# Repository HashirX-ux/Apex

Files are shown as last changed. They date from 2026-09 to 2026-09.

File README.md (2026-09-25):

# Apex


[]()
[]()
[]()
[]()
[]()
[]()`

---

## What is it?







## CAD





Apex is a custom **112 key full size** wireless mechanical keyboard I designed from the ground up after building a macropad and deciding a store bought board would never feel like mine.

The PCB is designed in **KiCad**, the case in **FreeCAD**, and the firmware is on **ZMK**. 

On top of a standard full size layout it adds:

- a **0.91" SSD1306 OLED** (128×32, I²C) for layer / battery / connection status
- an **EC11 rotary encoder** with push switch (volume and extras)
- an onboard **buzzer** driven by a 2N3904
- **per-key SK6812 Mini E** reverse mount RGB

---

## Why I built it

I wanted a Keyboard that belongs to me not to any company so I build my own keyboard. 

---

## Features

- 112 keys, full size layout (ANSI 104 + 8 extra keys)
- 8×14 col2row matrix
- Wireless BLE 5.0 via Nordic nRF52840 (AQFN- 73)
- USB C wired + wireless dual mode
- Per-key SK6812 Mini E RGB, reverse mounted
- Kailh MX hot-swap sockets  
- 0.91" OLED (SSD1306, 128×32, I²C)
- EC11 rotary encoder with push switch
- Onboard buzzer (2N3904 driver)
- 3.7 V LiPo 1500 mAh with MCP73831 charger
- 74AHCT125 level shifter for LED data (3.3 V → 5 V)
- USBLC6 2SC6 ESD protection on USB D+/D−
- 32 MHz crystal for the nRF52840
- ZMK firmware (USB + BLE, battery reporting, OLED, encoder, RGB)
- 2-layer PCB, KiCad, JLCPCB fabrication
- Custom 3D printed case designed in FreeCAD

---

ZMK is currently targeted at `nice_nano_v2` as a bring up stand in. The PCB carries a **bare nRF52840** (not a Pro Micro module). Pin mapping on the real board is still being finished see [Firmware](#flash-the-firmware).

---

## How to Build

### Order the PCB

1. Go to [JLCPCB](https://jlcpcb.com)
2. Upload the Gerbers from `pcb/gerber/gerber.rar`
3. 2-layer, FR 4, **1.6 mm**, HASL or **ENIG** (ENIG recommended for hot-swap pads and the AQFN-73)
4. Minimum order is 5 boards
5. Order a stencil for the nRF52840, SK6812 Mini-E, and other SMD parts the AQFN-73 is not a hand-solder-first footprint

### Flash the Firmware

Firmware lives in [`frimware/`](frimware/) and is a **ZMK skeleton**, not the final keymap.

1. Fork this repo (or copy `frimware/` into a [ZMK config](https://zmk.dev/docs/user-setup) repo)
2. Current build target in `frimware/build.yaml`:

   ```yaml
   include:
     - board: nice_nano_v2
       shield: apex
   ```

3. Edit the keymap at `frimware/config/apex.keymap`
4. Push GitHub Actions builds the `.uf2`
5. Download the artifact, double-tap reset to enter the bootloader, drag the `.uf2` onto the drive that appears

The overlay (`frimware/config/boards/shields/apex/apex.overlay`) is still a 5×14 bring up matrix. The PCB is **8×14 / 112 keys**. Next step is mapping the real nRF52840 pins, OLED, encoder, buzzer, and the 112 LED chain.

## BOM

> Estimated total: **~$230 USD** can drop to **$170–$200** buying locally and skipping extras (second switch pack, spare LEDs, extra PCBs).

Prices are typical AliExpress pack prices as of 2026. You buy the pack; you do not need every piece in it. Shipping not included.

| Component | Spec | Qty | Price | Notes | Link |
|---|---|---|---|---|---|
| Microcontroller | nRF52840-QIAA, AQFN-73 | ×1 | $5.00 | Bare Nordic SoC — BLE 5.0, 7×7 mm | [Buy](https://www.aliexpress.com/item/1005009698070392.html) |
| 74AHCT125 level shifter | TSSOP-14 | ×1 | $2.52 | Pack of 10 — LED data 3.3 V → 5 V | [Buy](https://www.aliexpress.com/item/1005008171122183.html) |
| MCP73831 LiPo charger | MCP73831-2-MC, DFN-8 3×2 mm | ×1 | $2.50 | Pack of 10 — **DFN-8 footprint**, not SOT-23-5 | [Buy](https://www.aliexpress.com/item/1005007439657191.html) |
| USBLC6-2SC6 ESD | SOT-23-6 | ×1 | $1.50 | Pack of 10 — USB D+/D− | [Buy](https://www.aliexpress.com/item/32807108222.html) |
| MX mechanical switches | 5-pin PCB mount | ×112 | $32.00 | Pack of 110–120 — Gateron / any MX 5-pin | [Buy](https://www.aliexpress.com/item/1005006091988869.html) |
| Kailh hot-swap socket | MX compatible, CPG151101S11 | ×112 | $14.00 | Pack of 100 × 2 | [Buy](https://www.aliexpress.com/item/1005006105603269.html) |
| SK6812 Mini-E RGB LED | Reverse mount, 3.2×2.8 mm | ×112 | $27.00 | Pack of 100 × 2 — buy 200, use 112 + spares | [Buy](https://www.aliexpress.com/item/1005004249903121.html) |
| 1N4148W matrix diode | SOD-123 | ×112 | $3.00 | Pack of 100 × 2 | [Buy](https://www.aliexpress.com/item/1005010728396328.html) |
| EC11 rotary encoder | 20 mm, with push switch | ×1 | $2.00 | Pack of 5 | [Buy](https://www.aliexpress.com/item/1005006460161288.html) |
| Rotary knob | Aluminum, 6 mm D-shaft, 20 mm | ×1 | $2.00 | 2 pieces | [Buy](https://www.aliexpress.com/item/4001091267351.html) |
| Reset button | SMD tactile, CK KMR2 | ×1 | $1.50 | Pack of 30 | [Buy](https://www.aliexpress.com/item/4001107416458.html) |
| OLED display | 0.91" 128×32 SSD1306 I²C | ×1 | $2.50 | ER-OLED0.91, address 0x3C | [Buy](https://www.aliexpress.com/item/1005004375650245.html) |
| Buzzer | 12×9.5 mm, 5 V | ×1 | $1.80 | Pack of 10 — matches 12×9.5 RM7.6 footprint | [Buy](https://www.aliexpress.com/item/4000829554492.html) |
| 2N3904 transistor | TO-92 | ×1 | $1.40 | Pack of 50 — buzzer driver | [Buy](https://www.aliexpress.com/w/wholesale-2n3904-transistor.html) |
| 32 MHz crystal | SMD 2016, 4-pin | ×1 | $1.80 | Pack of 10 — nRF52840 HFCLK | [Buy](https://www.aliexpress.com/w/wholesale-32mhz-crystal.html) |
| Status LED | 0603 SMD | ×1 | $1.00 | Pack of 100 — charger / power indicator | [Buy](https://www.aliexpress.com/w/wholesale-0603-smd-led.html) |
| Resistor 10 kΩ | 0603 | ×3 | $1.20 | Pack of 300 — I²C / reset pull-ups | [Buy](https://www.aliexpress.com/item/1005011779883974.html) |
| Resistor 5.1 kΩ | 0603 | ×2 | $1.30 | Pack of 300 — USB-C CC1/CC2 | [Buy](https://www.aliexpress.com/item/1005011779883974.html) |
| Resistor 330 Ω | 0603 | ×1 | $2.00 | Pack of 500 — buzzer base / LED | [Buy](https://www.aliexpress.com/item/1005005700395390.html) |
| Resistor 1 kΩ | 1206 + 0805 | ×2 | $1.20 | Pack of 300 — PROG / current limit | [Buy](https://www.aliexpress.com/item/1005011779883974.html) |
| Capacitor 100 nF | 0805 | ×119 | $2.00 | Pack of 200 — 112 LED + MCU decoupling | [Buy](https://www.aliexpress.com/item/1005007660078779.html) |
| Capacitor 12 pF | 0402 | ×2 | $1.50 | Pack of 100 — crystal load | [Buy](https://www.aliexpress.com/w/wholesale-0402-12pf-capacitor.html) |
| USB-C receptacle 16P | GCT USB4105 SMD | ×1 | $4.50 | Pack of 5 | [Buy](https://www.aliexpress.com/item/1005005581945089.html) |
| JST PH 2-pin | PH2.0, B2B-PH-K vertical | ×1 | $2.00 | Pack of 2 — battery connector | [Buy](https://www.aliexpress.com/item/1005010615395743.html) |
| Polyfuse 500 mA | Resettable, 1206 | ×1 | $1.70 | Pack of 10 | [Buy](https://www.aliexpress.com/item/1005005235906949.html) |
| LiPo 3.7 V 1500 mAh | JST PH 2.0 | ×1 | $5.80 | Size to fit the case tray | [Buy](https://www.aliexpress.com/item/1005010110802624.html) |
| Keycap set | PBT, full-size MX | ×104+ | $26.00 | 104-key set; extras needed for 112 | [Buy](https://www.aliexpress.com/w/wholesale-104-keycap-set.html) |
| PCB fabrication | 2-layer, FR-4, 1.6 mm, HASL/ENIG | ×5 boards | $32.00 | Full-size board — ENIG preferred | [JLCPCB](https://cart.jlcpcb.com/quote) |
| 3D print — case | FDM PETG / SLA resin | ×1 | $42.00 | FreeCAD sources in `cad/` — local print is cheaper | [JLC3DP](https://jlc3dp.com/3d-printing-quote) |
| M3 screws | M3 × 8 mm countersunk | ×10 | $1.00 | Pack of 50 | [Buy](https://www.aliexpress.com/item/1005008810897680.html) |
| M3 standoffs | M3 × 4–6 mm | ×10 | $1.00 | Pack of 50 | [Buy](https://www.aliexpress.com/item/1005008810897680.html) |

**BOM notes**

- The charger footprint on the PCB is **DFN-8 (MCP73831-2-MC)**. A SOT-23-5 MCP73831 will not fit without a bodge.
- SK6812 Mini-E must be the **reverse-mount** Mini-E, not SK6812 Mini or WS2812B 3535.
- Hot-swap sockets are **Kailh MX** (CPG151101S11), 1.00u. Stabilizers are still required on 2U+ keys (not listed — use your usual plate/PCB mount Cherry-style stabs).
- nRF52840 can run from VDDH (2.5–5.5 V high-voltage mode), which is why there is no separate 3.3 V LDO on this rev. LEDs are 5 V (`LED_5V` / VBUS).
- PROG resistor on the MCP73831 sets charge current (`IREG ≈ 1000 / RPROG`). 1 kΩ ≈ 1 A; 2 kΩ ≈ 500 mA. 500 mA is gentler on a 1500 mAh cell.

---

## Repository

```text
Apex/
├── cad/                  FreeCAD case + STEP
│   ├── APex cad.FCStd
│   └── .step
├── frimware/             ZMK config (skeleton)
│   ├── build.yaml
│   └── config/
│       ├── apex.conf
│       ├── apex.keymap
│       └── boards/shields/apex/
├── pcb/
│   ├── apex-pcb_design.kicad_sch
│   ├── apex-pcb_design.kicad_pcb
│   ├── LED-Design.kicad_sch
│   └── gerber/gerber.rar
├── Journal.md            Build log
└── LICENSE               MIT
```

---

## Credits

- [KiCad](https://www.kicad.org/)   PCB design
- [ZMK Firmware](https://zmk.dev/)   open-source wireless keyboard firmware
- [FreeCAD](https://www.freecad.org/)  case design
- [Nordic Semiconductor](https://www.nordicsemi.com/)   nRF52840
- [nice!nano](https://nicekeyboards.com/nice-nano/)   ZMK bring-up target
- Guides that got this off the ground: [nice!nano docs](https://nicekeyboards.com/docs/nice-nano/), [JLCPCB keyboard PCB guide](https://jlcpcb.com/blog/pcb-keyboards-design-guide), [Masterzen keyboard design series](https://www.masterzen.fr/2020/05/03/designing-a-keyboard-part-1/)

Made by **Hashir**  2026

---

## License

[MIT](LICENSE)

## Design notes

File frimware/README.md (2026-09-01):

# Apex firmware

this is the vibe check for the apex keyboard build

104 keys
wireless
nrf52840 vibe
nice nano style board
oled
rotary knob
buzzer
rgb
battery charging stuff

this is just the skeleton not the full final firmware
base setup is in zmk
main pieces are in the config folder

build yaml
apex conf
apex keymap
apex overlay

next up is mapping the real pcb pins and finishing the full key layout

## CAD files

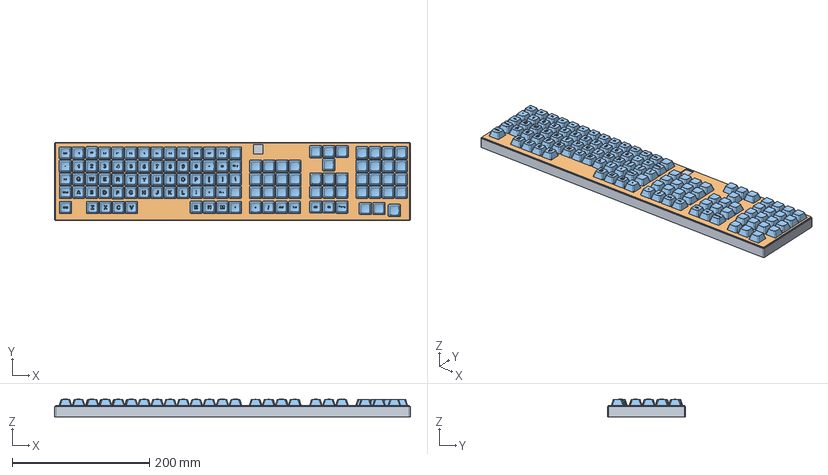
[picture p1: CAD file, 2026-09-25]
cad/keyboard_assembly.FCStd
519.4 x 114.3 x 25.9 mm
BaseTray
KeyboardPlate
KeyCaps
KeyLegends

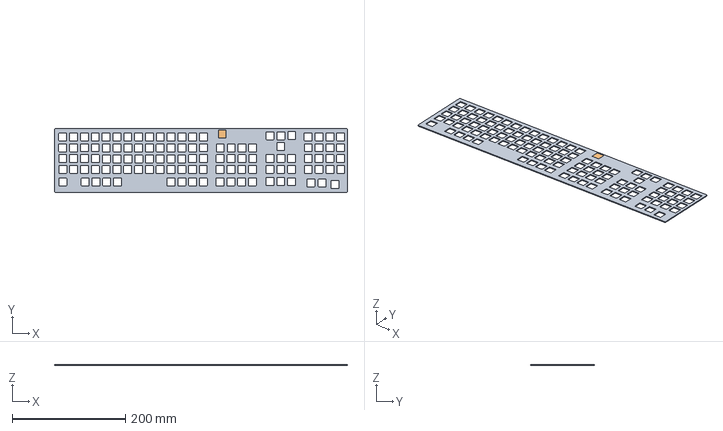
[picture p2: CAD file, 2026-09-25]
cad/plate.FCStd
516.6 x 112.1 x 1.50 mm

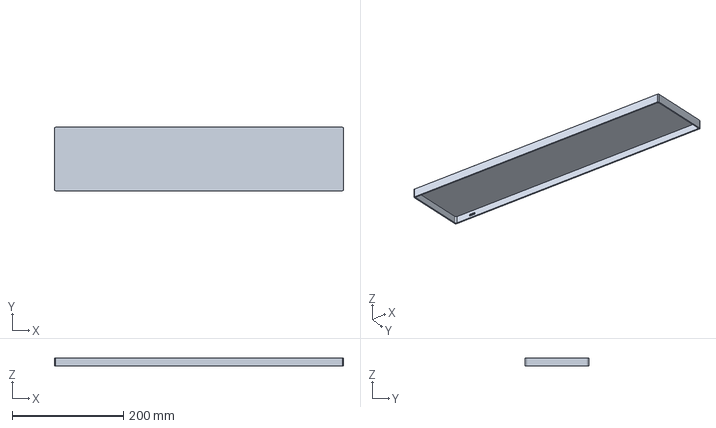
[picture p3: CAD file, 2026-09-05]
cad/APex cad.FCStd
519.4 x 114.3 x 15.0 mm

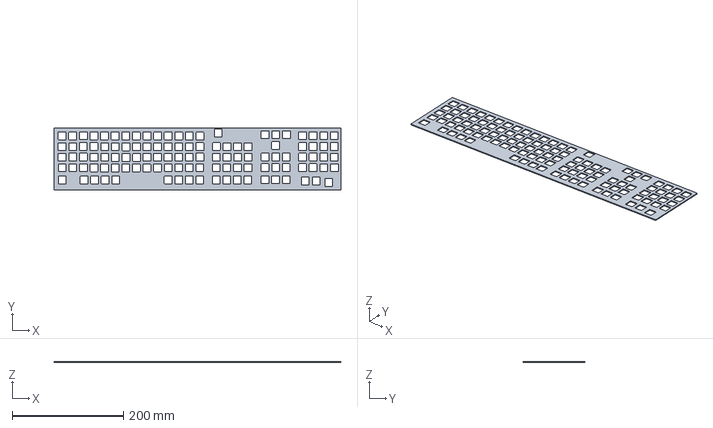
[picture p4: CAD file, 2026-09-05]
cad/apex_plate.step
516.6 x 112.1 x 1.50 mm

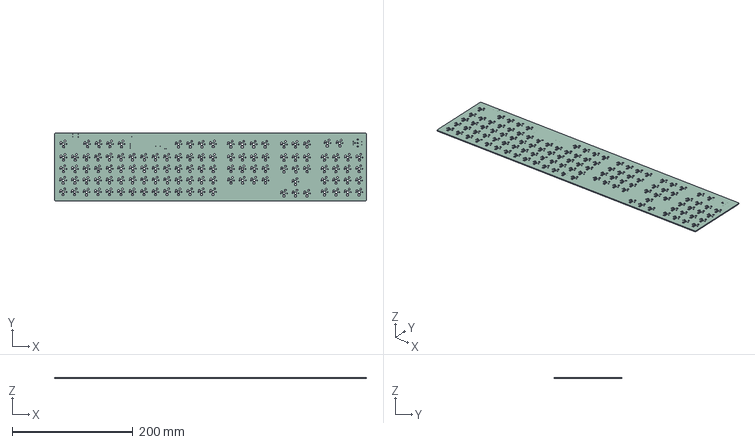
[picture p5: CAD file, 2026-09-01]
cad/.step
516.6 x 112.1 x 1.51 mm

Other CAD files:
cad/APex cad-Body.step

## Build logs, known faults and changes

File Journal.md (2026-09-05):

# Project Journal

**Project Name:** Apex  
**Start Date:** 2026-01-08  
**Status:** Completed

## Overview
Apex is a wireless mechanical keyboard built for productivity and daily tasks.

## Recent Entries

### 2026-01-08 - First Journal Entry

**What I did today:**

So This is my first time creating a keyboard. I have created a macropad before so I thought why not built a full keyboard of my own. So I did it duhh.. it was difficult but somehow I did it.. 
<br>

I am gonna start my research now.. Gonna start with the number of keys that i am gonna use: 

<br>
Guess I am gonna use standard keyboard keys which are 104 for the US/Canada type: 

<br>
So I researched a not for the MCU that I wass gonna use for my keybord and I found the nicennao v2 the best for that as it already contains built in crystal oscillator and voltage regulator which us gonna help me manage my schematic and make it less complexx..
<br>
So here are my main components that I am gonna use for my keyboard: 
<br>

1- MCU: nicenano! v2

<br>

2- 104-standard keys

<br>

3- OLED 0.91 inch

<br>

4- RotaryEncoder

<br>

5- Buzzer


5- Diodes

<br>

6- DeCoupling Caps

<br>

7- Reset Swtich
<br>

Now I gotta understand all of the datasheeeets.. Lets start by nicennao.. Wish me luck gngng..I am gonna use the official nicennao doc for this research: 
<br>
https://nicekeyboards.com/docs/nice-nano/
<br>
Found this keyboard config guide: https://www.nextpcb.com/blog/how-to-design-mechanical-keyboard-pcbs-with-kicad

<br>
One of the best guide I found out there gng .. 
<br>
https://www.modmusings.com/how-to-build-a-mechanical-keyboard
<br>
Thanks again the og documentation.. This is gonna help alot

<br>
So this is the schematic for the OLED i am gonna use its OLED 0.91: 

<br>
Didnt expected my rotary encoder to look like this under the hood: 

<br>
This would really help in designing the 3D cover case for my keyboard.. 

<br>
YOOO gng i think I just found a goldmine thank god i was looking for this: 
https://www.masterzen.fr/2020/05/03/designing-a-keyboard-part-1/
So Now I am Done with the research I am gonna start building the shcmeatic of my keyvaord and then The Final PCB design.. Wish me luck boisss.. 
<br>
### 2026-02-08 - First Journal Entry

**What I did today:**
So Today I am gonna start building the shcematic of my keyboard.. I am gonna use the official guide from PCBWay and JLCPCB for their keyboard design guide: 
<br>
https://jlcpcb.com/blog/pcb-keyboards-design-guide
<br>
So I am gonna build the schematic using this layout: 

<br>
The MCU looks good.. its nice and nano nicenano!!!

<br>
So this is my first key and I have to compleye like 112 of them.. wish me luck gng: 

<br>
So far so good gng yayay: 

Looks good gng.. i need to structure it: 

<br>
Done with the key matrix.. Loooks finne gng: 

<br>
So I just realised that my mcu has shorter pins to the number of pins I need so i gotta look up for some other mcu :(.. So i found ESP-S3 for my keyboard as it has 45! gp pins and nicennao only has .. LAME NICENNAO: 

<br>

<br>
The schematic is massive gng 

<br>
Now I am gonna start building the crystal oscillator using this guide: 
<br>
https://forum.kicad.info/t/solved-what-is-a-proper-way-to-model-xtal-in-kicad/22954

<br>
Looks good But u still gotta make some tweaks.... 

<br>
CHANGE IN PLAN I REPEAT CHANGE IN PLAN!!.. I just found that I can just use Nordic nRF52840.. Gosh my 2 braincells cant figure ts out.. 

<br>
So Now I gonna finish my rotary encoder

<br>
Now Gotta build the charger: 

<br>
The LED voltage regulator looks good.. 

<br>
Holy hell

<br>
im genius IM just GENIUS

<br>
Almost done with the rgb lights.. 

<br>
So far so good ..

Done with the LEDs ayayay

<br>
So I finally done with the schematic Now ILL be moving towards routing.. 

<br>

I have no idea how am I even gonna route ts.. wish me luck bois.. 

<br>
Structure is complete.. Now I just gotta route it.. whish me luck gng..

So far so good gng :D

Yoo why ts looks this ugly.. 

<br>
How am I even suppose to route ts..


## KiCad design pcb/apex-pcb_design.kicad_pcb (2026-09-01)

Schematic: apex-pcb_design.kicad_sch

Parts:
BZ1: Buzzer; Buzzer_12x9.5RM7.6
C1, C2: 12pF; C_0402_1005Metric
C3, C4, C5, C6, C7, C8, C121: 100nF; C_0805_2012Metric_Pad1.18x1.45mm_HandSolder
D1, D2, D3, D4, D5, D6, D7, D8, D9, D10, D11, D12, D13, D14, D15, D16, D17, D18, D19, D20, D21, D22, D23, D24, D25, D26, D27, D28, D29, D30, D31, D32, D33, D34, D35, D36, D37, D38, D39, D40, D41, D42, D43, D44, D45, D46, D47, D48, D49, D50, D51, D52, D53, D54, D55, D56, D57, D58, D59, D60, D61, D62, D63, D64, D65, D66, D67, D68, D69, D70, D71, D72, D73, D74, D75, D76, D77, D78, D79, D80, D81, D82, D83, D84, D85, D86, D87, D88, D89, D90, D91, D92, D93, D94, D95, D96, D97, D98, D99, D100, D101, D102, D103, D104, D105, D106, D107, D108, D109, D110, D111, D112: 1N4148; D_SOD-123
D113: LED; LED_0603_1608Metric
D115: SK6812MINI-E; LED_SK6812MINI-E_3.2x2.8mm_P1.5mm_ReverseMount
F1: 500mA; Fuse_1206_3216Metric
J1: USB_C_Receptacle_USB2.0_16P; USB_C_Receptacle_GCT_USB4105-xx-A_16P_TopMnt_Horizontal
J2: 1500mAh; JST_PH_B2B-PH-K_1x02_P2.00mm_Vertical
Q1: 2N3904; TO-92_Inline
R1, R2, R8: 10k; R_0603_1608Metric_Pad0.98x0.95mm_HandSolder
R5, R6: 5.1k; R_0603_1608Metric_Pad0.98x0.95mm_HandSolder
R7: 1k; R_1206_3216Metric
R9: 1k; R_0805_2012Metric
R10: 330R; R_0603_1608Metric_Pad0.98x0.95mm_HandSolder
SW1, SW2, SW3, SW4, SW5, SW6, SW7, SW8, SW9, SW10, SW11, SW12, SW13, SW14, SW15, SW16, SW17, SW18, SW19, SW20, SW21, SW22, SW23, SW24, SW25, SW26, SW27, SW28, SW29, SW30, SW31, SW32, SW33, SW34, SW35, SW36, SW37, SW38, SW39, SW40, SW41, SW42, SW43, SW44, SW45, SW46, SW47, SW48, SW49, SW50, SW51, SW52, SW53, SW54, SW55, SW56, SW57, SW58, SW59, SW60, SW61, SW62, SW63, SW64, SW65, SW66, SW67, SW68, SW69, SW70, SW71, SW72, SW73, SW74, SW75, SW76, SW77, SW78, SW79, SW80, SW81, SW82, SW83, SW84, SW85, SW86, SW87, SW88, SW89, SW90, SW91, SW92, SW93, SW94, SW95, SW96, SW97, SW98, SW99, SW100, SW101, SW102, SW103, SW104, SW105, SW106, SW107, SW108, SW109, SW110, SW111, SW112: SW_Push; SW_Hotswap_Kailh_MX_1.00u
SW113: RotaryEncoder_Switch; RotaryEncoder_Alps_EC11E-Switch_Vertical_H20mm_MountingHoles
SW114: SW_Push; SW_Push_1P1T_NO_CK_KMR2
U1: ER_OLEDM0.91_1x-I2C
U2: USBLC6-2SC6; SOT-23-6
U3: MCP73831-2-MC; DFN-8-1EP_3x2mm_P0.5mm_EP1.7x1.4mm
U4: nRF52840; Nordic_AQFN-73-1EP_7x7mm_P0.5mm
U5: 74AHCT125; TSSOP-14_4.4x5mm_P0.65mm
Y1: 32MHz; Crystal_SMD_2016-4Pin_2.0x1.6mm

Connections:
+3.3V: BZ1.1 (+), C5.1, C6.1, C7.1, C8.1, C121.1, R1.1, R2.1, U1.2 (VCC), U4.A22 (VDD), U4.AD14 (VDD), U4.AD23 (VDD), U4.B1 (VDD), U4.W1 (VDD)
BUZZER: BZ1.2 (-), Q1.3 (C)
COL0: SW1.2, SW15.2, SW29.2, SW43.2, SW57.2, SW71.2, SW85.2, SW99.2, U4.AD8 (P0.13)
COL1: SW2.2, SW16.2, SW30.2, SW44.2, SW58.2, SW72.2, SW86.2, SW100.2, U4.AC9 (P0.14)
COL2: SW3.2, SW17.2, SW31.2, SW45.2, SW59.2, SW73.2, SW87.2, SW101.2, U4.AD10 (P0.15)
COL3: SW4.2, SW18.2, SW32.2, SW46.2, SW60.2, SW74.2, SW88.2, SW102.2, U4.AC11 (P0.16)
COL4: SW5.2, SW19.2, SW33.2, SW47.2, SW61.2, SW75.2, SW89.2, SW103.2, U4.AD12 (P0.17)
COL5: SW6.2, SW20.2, SW34.2, SW48.2, SW62.2, SW76.2, SW90.2, SW104.2, U4.AC15 (P0.19)
COL6: SW7.2, SW21.2, SW35.2, SW49.2, SW63.2, SW77.2, SW91.2, SW105.2, U4.AD16 (P0.20)
COL7: SW8.2, SW22.2, SW36.2, SW50.2, SW64.2, SW78.2, SW92.2, SW106.2, U4.AC17 (P0.21)
COL8: SW9.2, SW23.2, SW37.2, SW51.2, SW65.2, SW79.2, SW93.2, SW107.2, U4.AD18 (P0.22)
COL9: SW10.2, SW24.2, SW38.2, SW52.2, SW66.2, SW80.2, SW94.2, SW108.2, U4.AC19 (P0.23)
COL10: SW11.2, SW25.2, SW39.2, SW53.2, SW67.2, SW81.2, SW95.2, SW109.2, U4.AD20 (P0.24)
COL11: SW12.2, SW26.2, SW40.2, SW54.2, SW68.2, SW82.2, SW96.2, SW110.2, U4.AC21 (P0.25)
COL12: SW13.2, SW27.2, SW41.2, SW55.2, SW69.2, SW83.2, SW97.2, SW111.2, U4.G1 (P0.26)
COL13: SW14.2, SW28.2, SW42.2, SW56.2, SW70.2, SW84.2, SW98.2, SW112.2, U4.H2 (P0.27)
ENC_A: R1.2, SW113.A, U4.A20 (P1.10)
ENC_B: R2.2, SW113.B, U4.B19 (P1.11)
GND: C1.1, C2.2, C3.2, C4.2, C5.2, C6.2, C7.2, C8.2, C121.2, D115.1 (VSS), J1.A1 (GND), J1.A12 (GND), J1.B1 (GND), J1.B12 (GND), J1.SH (SHIELD), J2.2, Q1.1 (E), R5.2, R6.2, R7.2, R8.1, SW113.C, SW114.1, U1.1 (GND), U2.2 (GND), U3.6 (V_{SS}), U4.B7 (VSS), U4.EP (VSS), U4.F23 (VSS_PA), U5.1, U5.7 (GND), Y1.2; also elsewhere on the board
LED_5V: R10.1, U5.3
LED_DATA_3V3: U4.R1 (TRACEDATA3/P1.09), U5.2
unnamed: D1.2 (A), SW1.1
unnamed: D2.2 (A), SW2.1
unnamed: D3.2 (A), SW3.1
unnamed: D4.2 (A), SW4.1
unnamed: D5.2 (A), SW5.1
unnamed: D6.2 (A), SW6.1
unnamed: D7.2 (A), SW7.1
unnamed: D8.2 (A), SW8.1
unnamed: D9.2 (A), SW9.1
unnamed: D10.2 (A), SW10.1
unnamed: D11.2 (A), SW11.1
unnamed: D12.2 (A), SW12.1
unnamed: D13.2 (A), SW13.1
unnamed: D14.2 (A), SW14.1
unnamed: D15.2 (A), SW15.1
unnamed: D16.2 (A), SW16.1
unnamed: D17.2 (A), SW17.1
unnamed: D18.2 (A), SW18.1
unnamed: D19.2 (A), SW19.1
unnamed: D20.2 (A), SW20.1
unnamed: D21.2 (A), SW21.1
unnamed: D22.2 (A), SW22.1
unnamed: D23.2 (A), SW23.1
unnamed: D24.2 (A), SW24.1
unnamed: D25.2 (A), SW25.1
unnamed: D26.2 (A), SW26.1
unnamed: D27.2 (A), SW27.1
unnamed: D28.2 (A), SW28.1
unnamed: D29.2 (A), SW29.1
unnamed: D30.2 (A), SW30.1
unnamed: D31.2 (A), SW31.1
unnamed: D32.2 (A), SW32.1
unnamed: D33.2 (A), SW33.1
unnamed: D34.2 (A), SW34.1
unnamed: D35.2 (A), SW35.1
unnamed: D36.2 (A), SW36.1
unnamed: D37.2 (A), SW37.1
unnamed: D38.2 (A), SW38.1
unnamed: D39.2 (A), SW39.1
unnamed: D40.2 (A), SW40.1
unnamed: D41.2 (A), SW41.1
unnamed: D42.2 (A), SW42.1
unnamed: D43.2 (A), SW43.1
unnamed: D44.2 (A), SW44.1
unnamed: D45.2 (A), SW45.1
unnamed: D46.2 (A), SW46.1
unnamed: D47.2 (A), SW47.1
unnamed: D48.2 (A), SW48.1
unnamed: D49.2 (A), SW49.1
unnamed: D50.2 (A), SW50.1
unnamed: D51.2 (A), SW51.1
unnamed: D52.2 (A), SW52.1
unnamed: D53.2 (A), SW53.1
unnamed: D54.2 (A), SW54.1
unnamed: D55.2 (A), SW55.1
unnamed: D56.2 (A), SW56.1
unnamed: D57.2 (A), SW57.1
unnamed: D58.2 (A), SW58.1
unnamed: D59.2 (A), SW59.1
unnamed: D60.2 (A), SW60.1
unnamed: D61.2 (A), SW61.1
unnamed: D62.2 (A), SW62.1
unnamed: D63.2 (A), SW63.1
unnamed: D64.2 (A), SW64.1
unnamed: D65.2 (A), SW65.1
unnamed: D66.2 (A), SW66.1
unnamed: D67.2 (A), SW67.1
unnamed: D68.2 (A), SW68.1
unnamed: D69.2 (A), SW69.1
unnamed: D70.2 (A), SW70.1
unnamed: D71.2 (A), SW71.1
unnamed: D72.2 (A), SW72.1
unnamed: D73.2 (A), SW73.1
unnamed: D74.2 (A), SW74.1
unnamed: D75.2 (A), SW75.1
unnamed: D76.2 (A), SW76.1
unnamed: D77.2 (A), SW77.1
unnamed: D78.2 (A), SW78.1
unnamed: D79.2 (A), SW79.1
unnamed: D80.2 (A), SW80.1
unnamed: D81.2 (A), SW81.1
unnamed: D82.2 (A), SW82.1
unnamed: D83.2 (A), SW83.1
unnamed: D84.2 (A), SW84.1
unnamed: D85.2 (A), SW85.1
unnamed: D86.2 (A), SW86.1
unnamed: D87.2 (A), SW87.1
unnamed: D88.2 (A), SW88.1
unnamed: D89.2 (A), SW89.1
unnamed: D90.2 (A), SW90.1
unnamed: D91.2 (A), SW91.1
unnamed: D92.2 (A), SW92.1
unnamed: D93.2 (A), SW93.1
unnamed: D94.2 (A), SW94.1
unnamed: D95.2 (A), SW95.1
unnamed: D96.2 (A), SW96.1
unnamed: D97.2 (A), SW97.1
unnamed: D98.2 (A), SW98.1
unnamed: D99.2 (A), SW99.1
unnamed: D100.2 (A), SW100.1
unnamed: D101.2 (A), SW101.1
unnamed: D102.2 (A), SW102.1
unnamed: D103.2 (A), SW103.1
unnamed: D104.2 (A), SW104.1
unnamed: D105.2 (A), SW105.1
unnamed: D106.2 (A), SW106.1
unnamed: D107.2 (A), SW107.1
unnamed: D108.2 (A), SW108.1
unnamed: D109.2 (A), SW109.1
unnamed: D110.2 (A), SW110.1
unnamed: D111.2 (A), SW111.1
unnamed: D112.2 (A), SW112.1
unnamed: D113.1 (K), R7.1
unnamed: J1.A5 (CC1), R5.1
unnamed: J1.B5 (CC2), R6.1
unnamed: R8.2, U3.8 (PROG)
unnamed: C1.2, U4.B24 (XC1), Y1.1
unnamed: C2.1, U4.A23 (XC2), Y1.3
RESET: SW114.2, U4.AC13 (P0.18/~RESET)
RES_IN: R9.1, U4.B17 (P1.12)
RES_OUT: Q1.2 (B), R9.2
ROW0: D1.1 (K), D2.1 (K), D3.1 (K), D4.1 (K), D5.1 (K), D6.1 (K), D7.1 (K), D8.1 (K), D9.1 (K), D10.1 (K), D11.1 (K), D12.1 (K), D13.1 (K), D14.1 (K), U4.Y23 (P1.01)
ROW1: D15.1 (K), D16.1 (K), D17.1 (K), D18.1 (K), D19.1 (K), D20.1 (K), D21.1 (K), D22.1 (K), D23.1 (K), D24.1 (K), D25.1 (K), D26.1 (K), D27.1 (K), D28.1 (K), U4.W24 (P1.02)
ROW2: D29.1 (K), D30.1 (K), D31.1 (K), D32.1 (K), D33.1 (K), D34.1 (K), D35.1 (K), D36.1 (K), D37.1 (K), D38.1 (K), D39.1 (K), D40.1 (K), D41.1 (K), D42.1 (K), U4.V23 (P1.03)
ROW3: D43.1 (K), D44.1 (K), D45.1 (K), D46.1 (K), D47.1 (K), D48.1 (K), D49.1 (K), D50.1 (K), D51.1 (K), D52.1 (K), D53.1 (K), D54.1 (K), D55.1 (K), D56.1 (K), U4.U24 (P1.04)
ROW4: D57.1 (K), D58.1 (K), D59.1 (K), D60.1 (K), D61.1 (K), D62.1 (K), D63.1 (K), D64.1 (K), D65.1 (K), D66.1 (K), D67.1 (K), D68.1 (K), D69.1 (K), D70.1 (K), U4.T23 (P1.05)
ROW5: D71.1 (K), D72.1 (K), D73.1 (K), D74.1 (K), D75.1 (K), D76.1 (K), D77.1 (K), D78.1 (K), D79.1 (K), D80.1 (K), D81.1 (K), D82.1 (K), D83.1 (K), D84.1 (K), U4.R24 (P1.06)
ROW6: D85.1 (K), D86.1 (K), D87.1 (K), D88.1 (K), D89.1 (K), D90.1 (K), D91.1 (K), D92.1 (K), D93.1 (K), D94.1 (K), D95.1 (K), D96.1 (K), D97.1 (K), D98.1 (K), U4.P23 (P1.07)
ROW7: D99.1 (K), D100.1 (K), D101.1 (K), D102.1 (K), D103.1 (K), D104.1 (K), D105.1 (K), D106.1 (K), D107.1 (K), D108.1 (K), D109.1 (K), D110.1 (K), D111.1 (K), D112.1 (K), U4.P2 (P1.08)
SCL: U1.3 (SCL), U4.A16 (P1.13)
SDA: U1.4 (SDA), U4.B15 (P1.14)
STAT: D113.2 (A), U3.5 (STAT)
USB_D+: J1.A6 (D+), J1.B6 (D+), U2.3 (I/O2), U4.AD6 (D+)
USB_D-: J1.A7 (D-), J1.B7 (D-), U2.1 (I/O1), U4.AD4 (D-)
VBAT: J2.1, U3.3 (V_{BAT}), U3.4 (V_{BAT}), U4.Y2 (VDDH)
VBUS: C3.1, C4.1, D115.3 (VDD), F1.1, F1.2, J1.A4 (VBUS), J1.A9 (VBUS), J1.B4 (VBUS), J1.B9 (VBUS), U2.4 (I/O2), U3.1 (V_{DD}), U3.2 (V_{DD}), U4.AD2 (VBUS), U5.4, U5.10, U5.13, U5.14 (VCC); also elsewhere on the board

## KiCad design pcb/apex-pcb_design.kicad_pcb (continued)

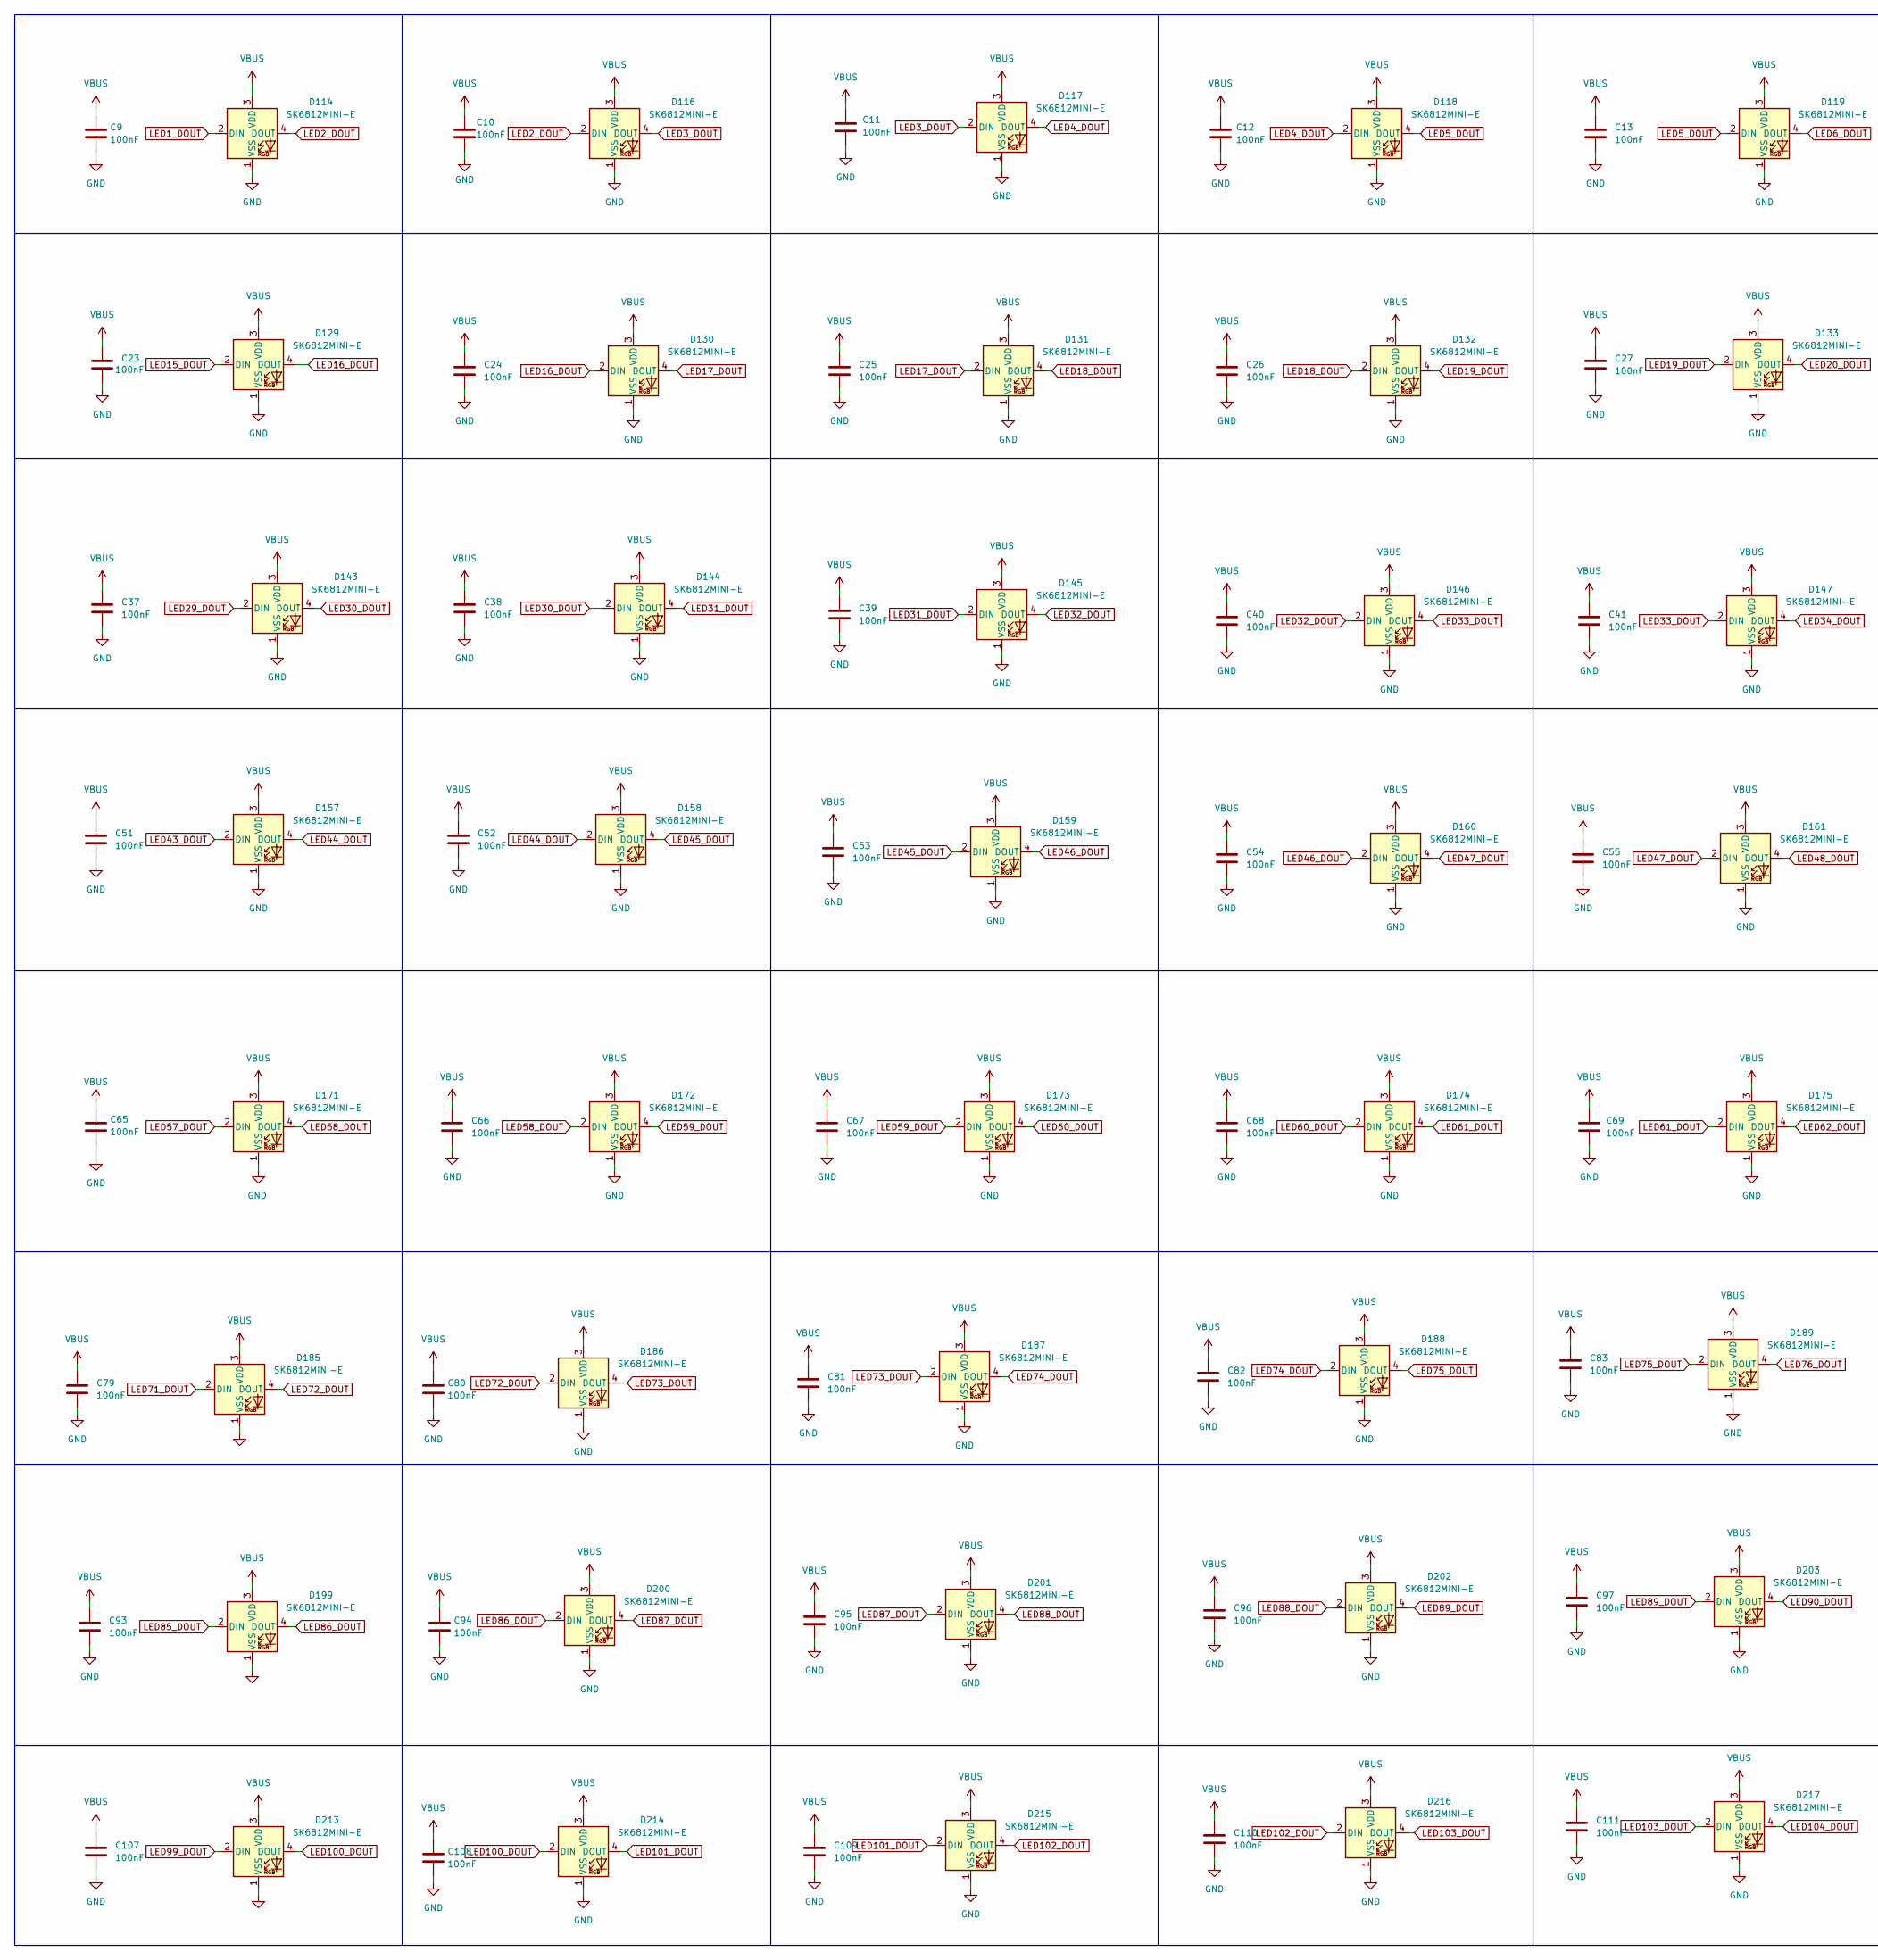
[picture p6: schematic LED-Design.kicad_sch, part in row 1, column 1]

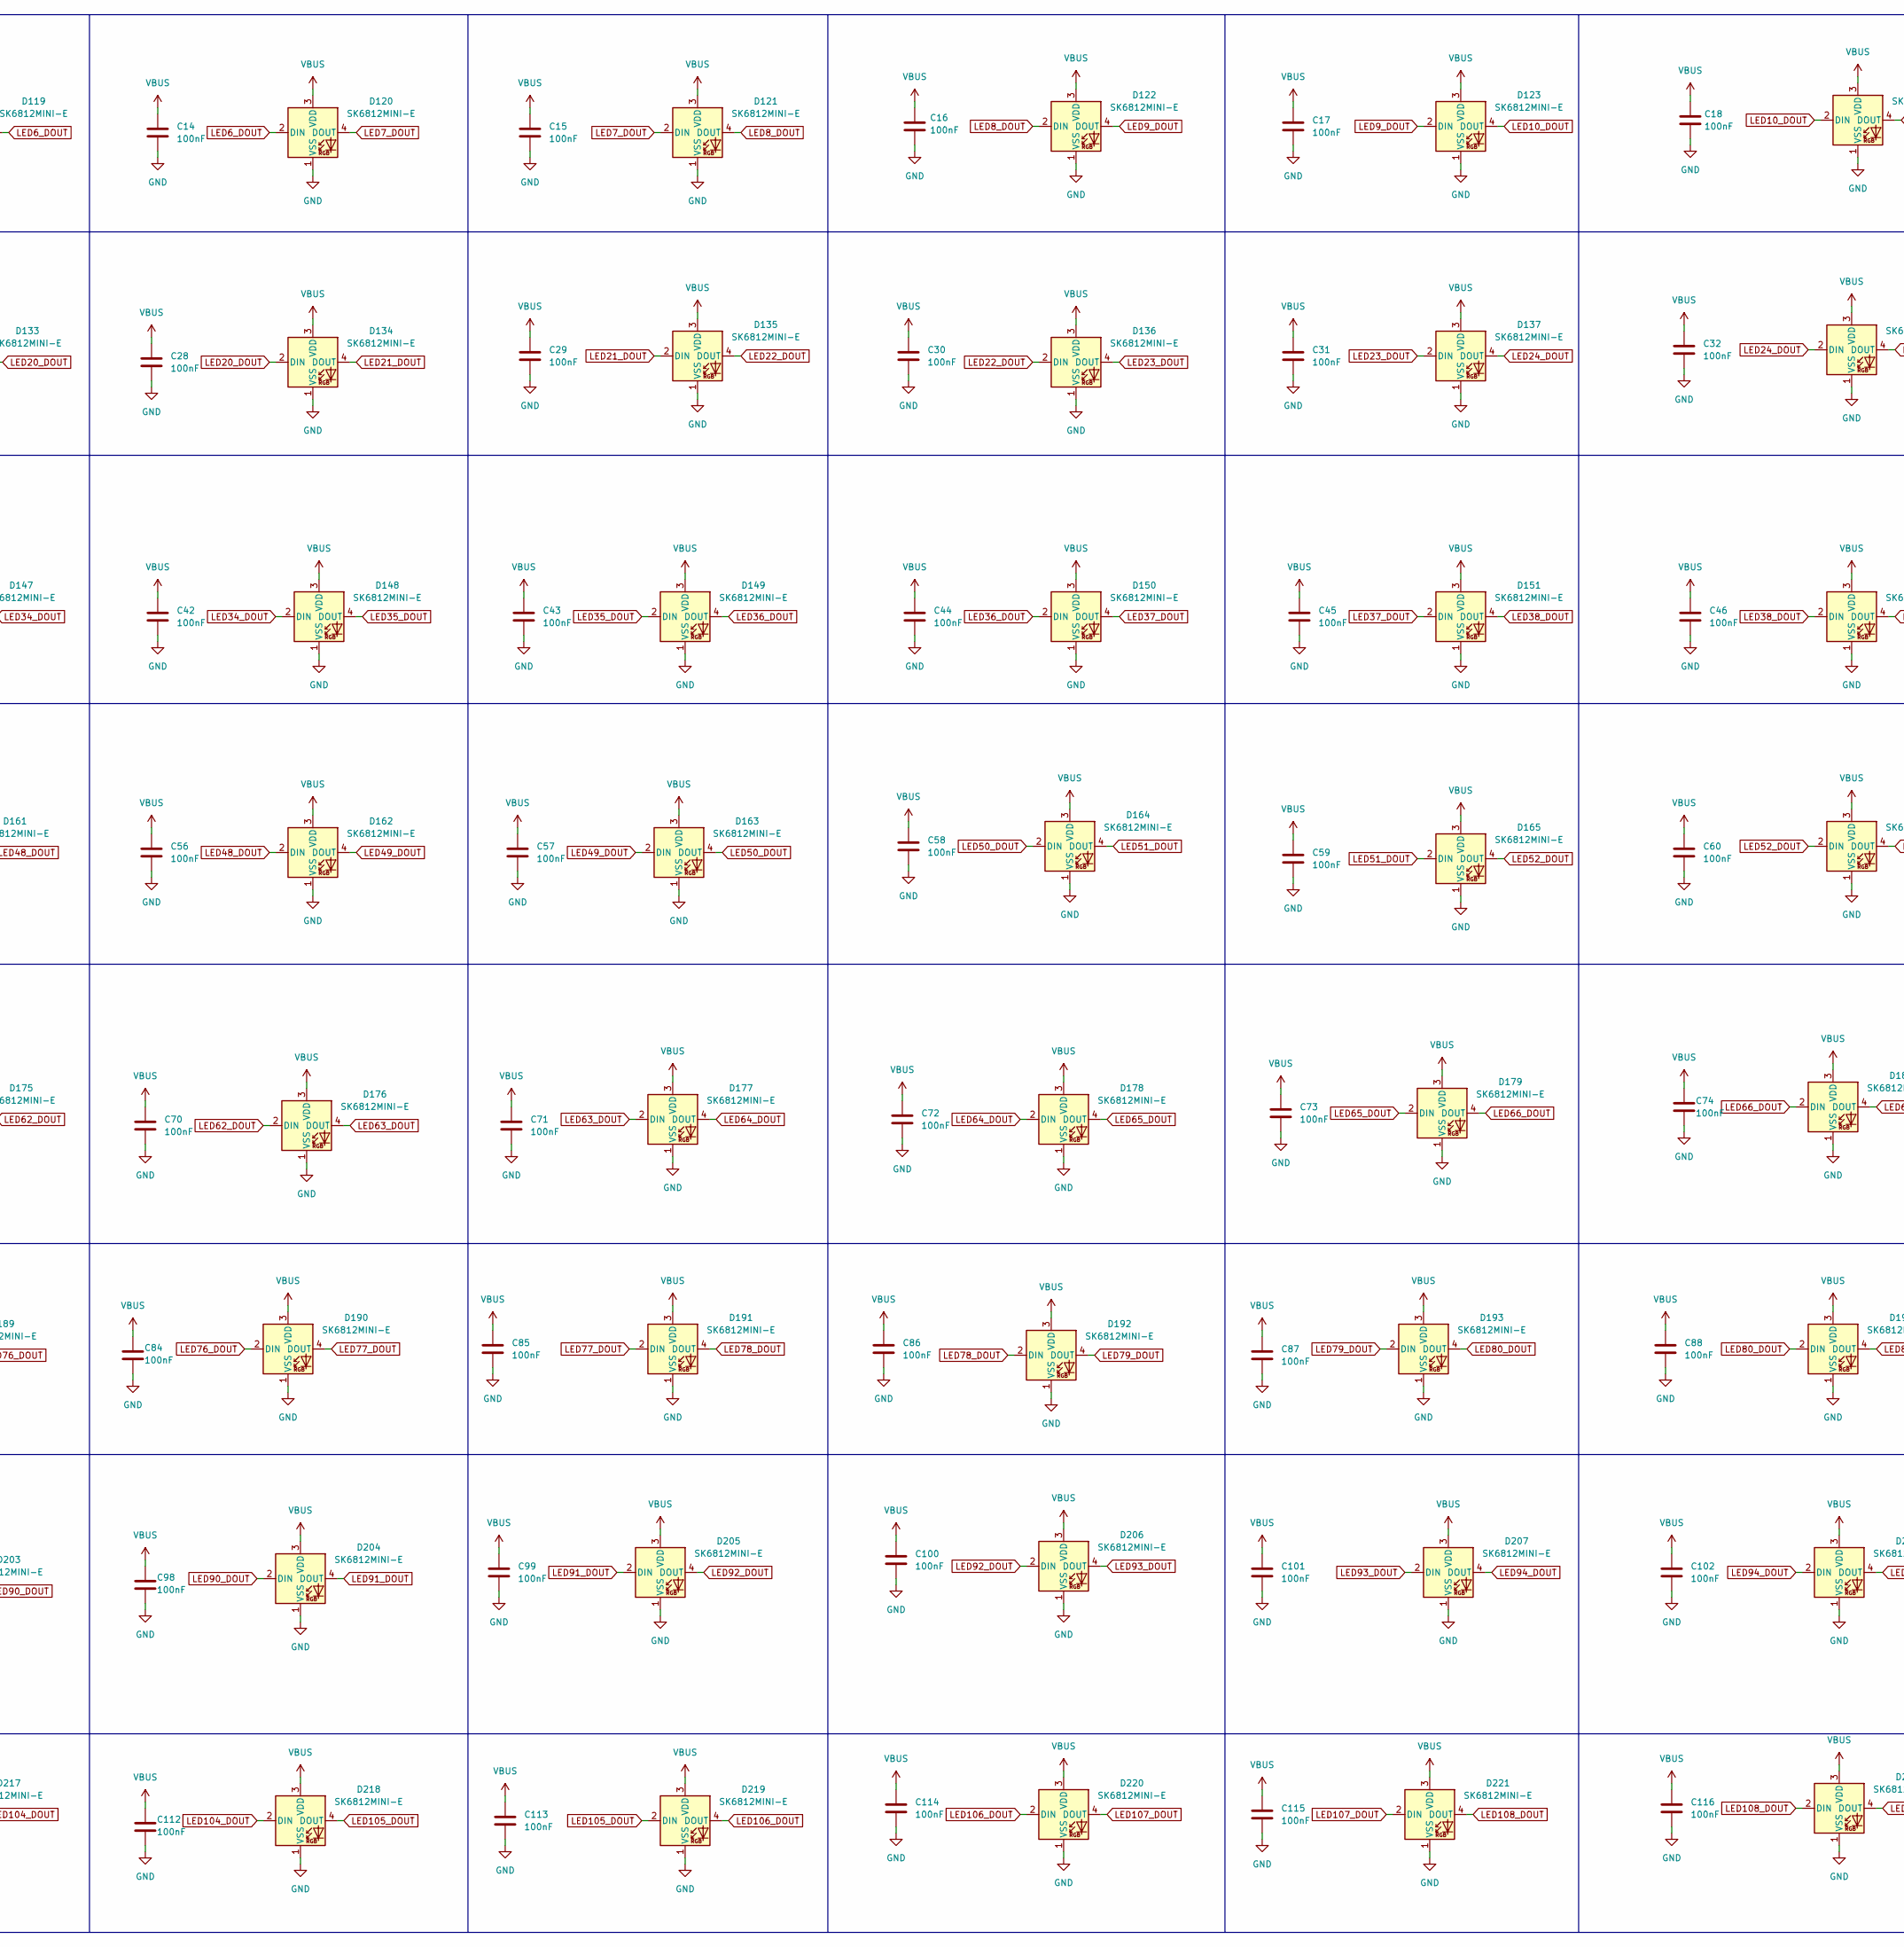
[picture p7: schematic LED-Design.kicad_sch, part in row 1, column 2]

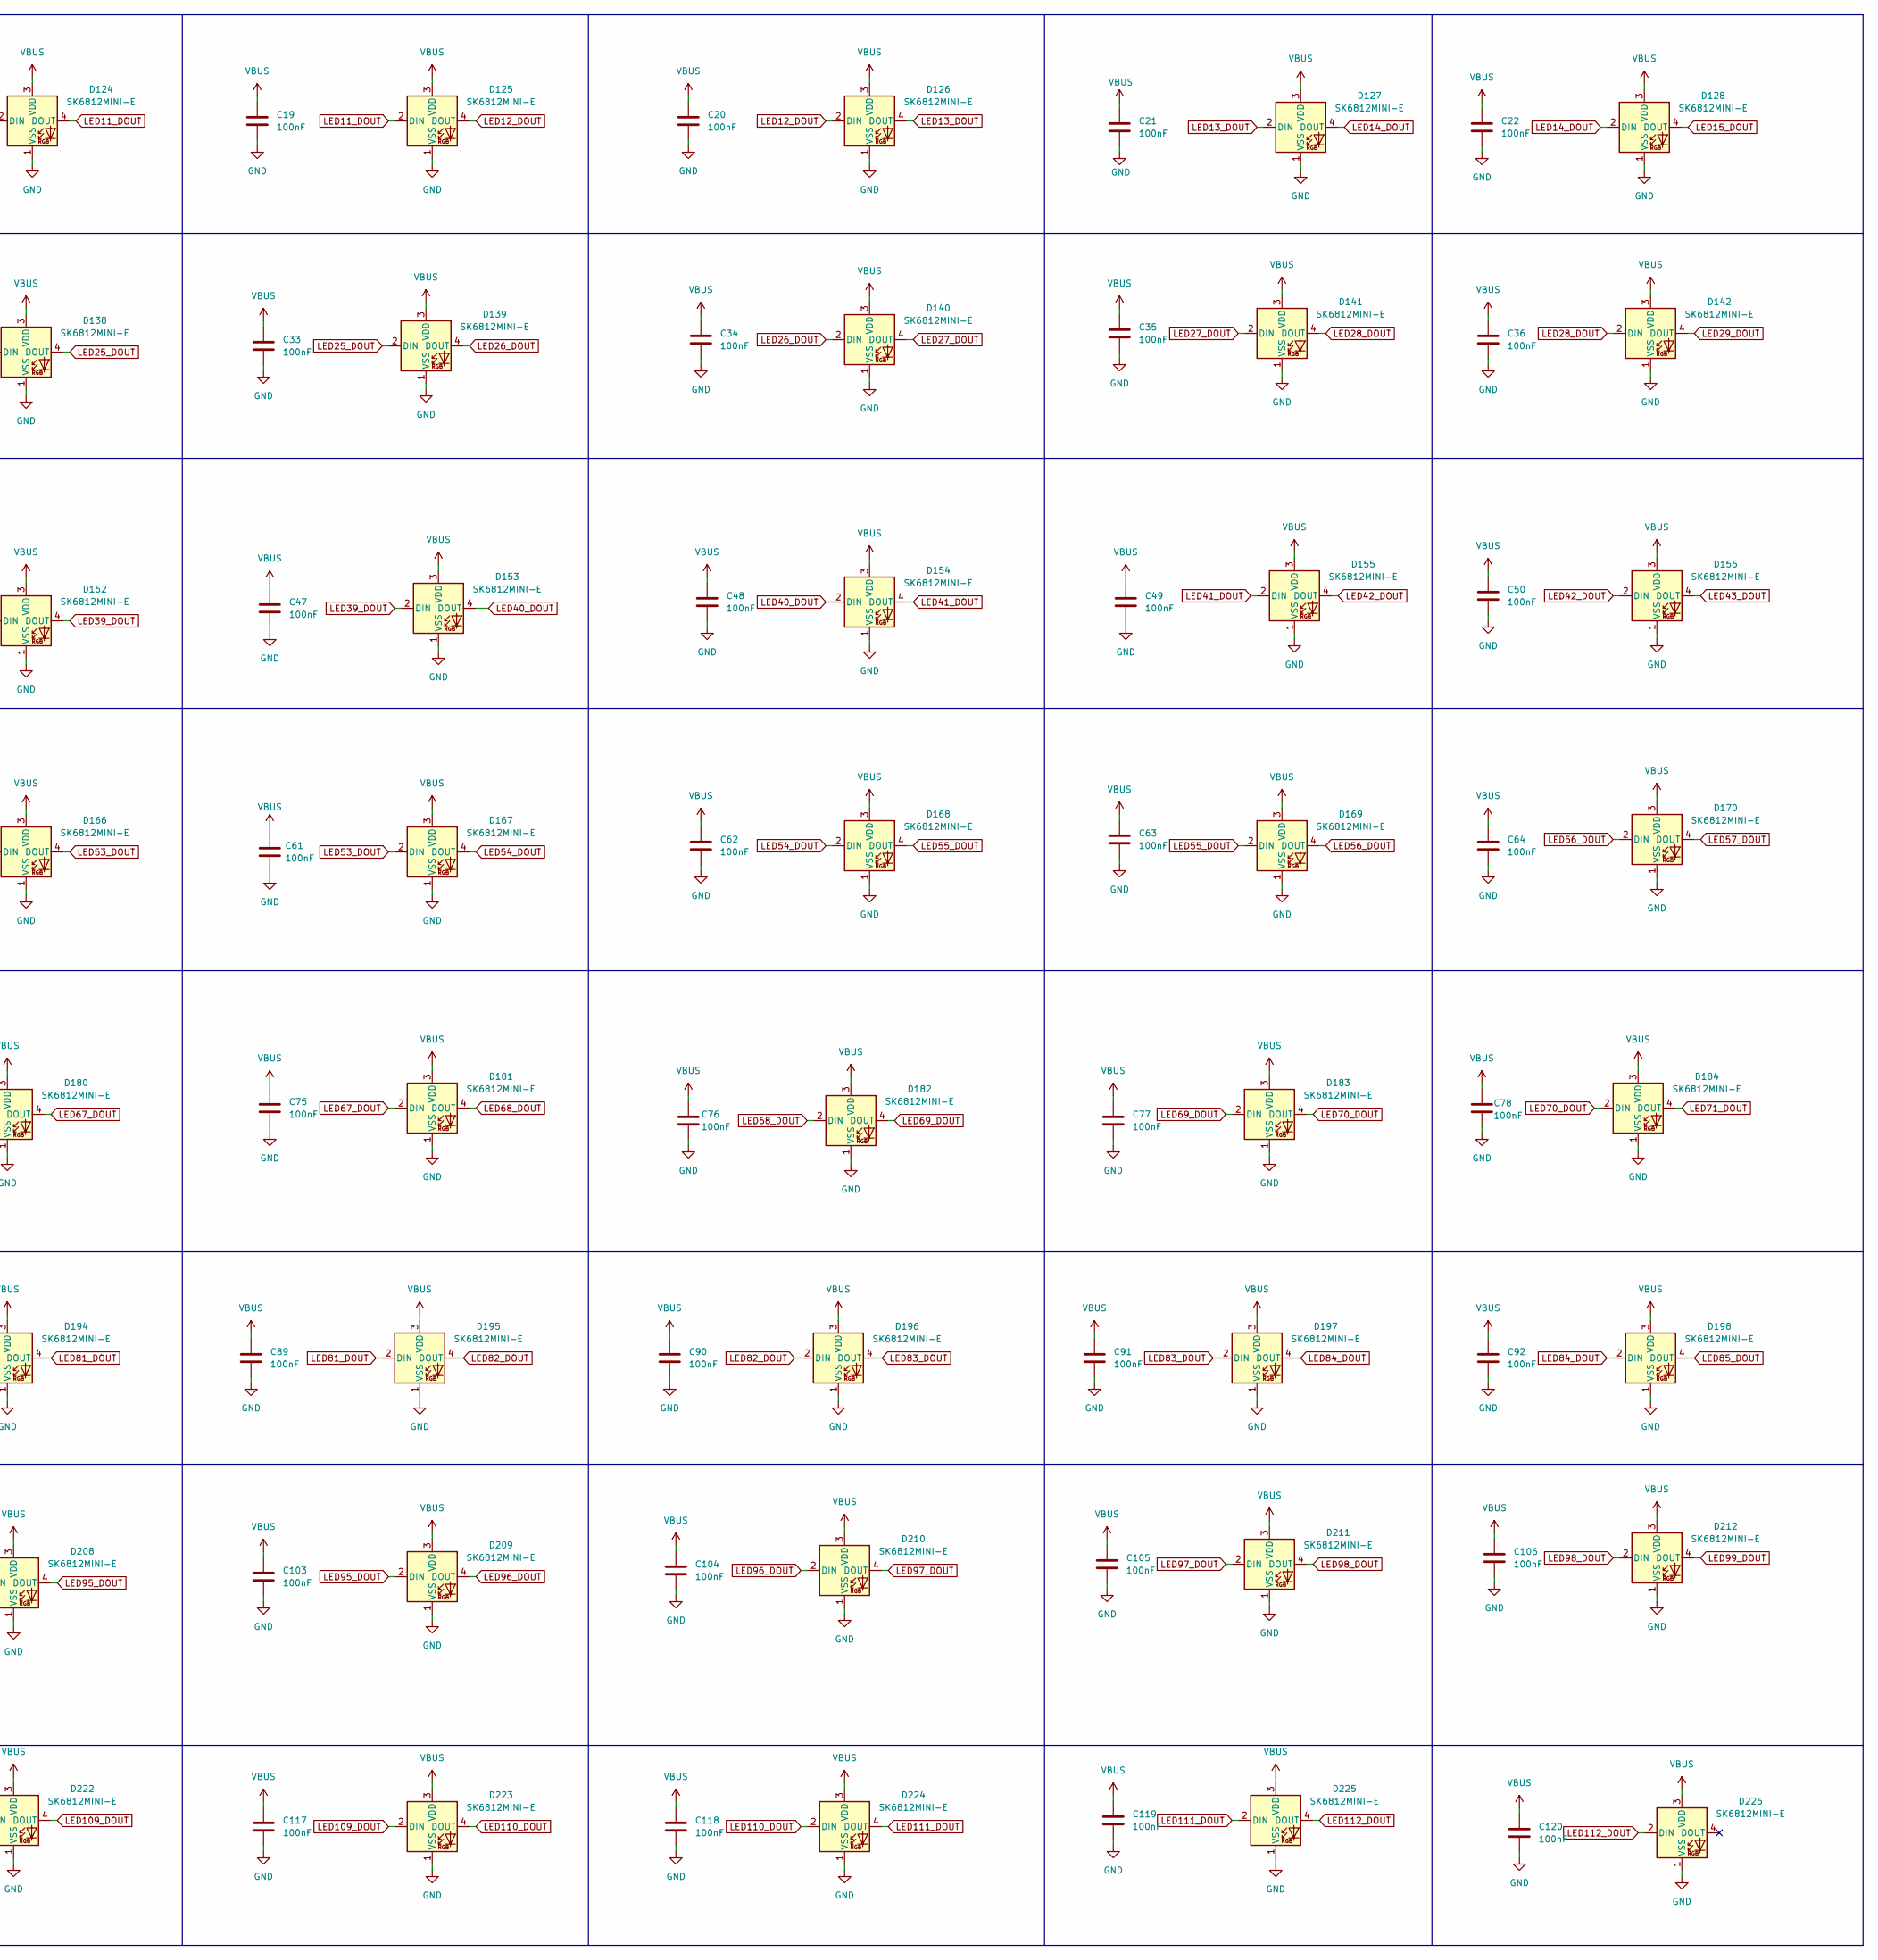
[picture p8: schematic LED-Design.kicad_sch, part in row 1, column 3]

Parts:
C9, C10, C11, C12, C13, C14, C15, C16, C17, C18, C19, C20, C21, C22, C23, C24, C25, C26, C27, C28, C29, C30, C31, C32, C33, C34, C35, C36, C37, C38, C39, C40, C41, C42, C43, C44, C45, C46, C47, C48, C49, C50, C51, C52, C53, C54, C55, C56, C57, C58, C59, C60, C61, C62, C63, C64, C65, C66, C67, C68, C69, C70, C71, C72, C73, C74, C75, C76, C77, C78, C79, C80, C81, C82, C83, C84, C85, C86, C87, C88, C89, C90, C91, C92, C93, C94, C95, C96, C97, C98, C99, C100, C101, C102, C103, C104, C105, C106, C107, C108, C109, C110, C111, C112, C113, C114, C115, C116, C117, C118, C119, C120: 100nF; C_0805_2012Metric_Pad1.18x1.45mm_HandSolder
D114, D116, D117, D118, D119, D120, D121, D122, D123, D124, D125, D126, D127, D128, D129, D130, D131, D132, D133, D134, D135, D136, D137, D138, D139, D140, D141, D142, D143, D144, D145, D146, D147, D148, D149, D150, D151, D152, D153, D154, D155, D156, D157, D158, D159, D160, D161, D162, D163, D164, D165, D166, D167, D168, D169, D170, D171, D172, D173, D174, D175, D176, D177, D178, D179, D180, D181, D182, D183, D184, D185, D186, D187, D188, D189, D190, D191, D192, D193, D194, D195, D196, D197, D198, D199, D200, D201, D202, D203, D204, D205, D206, D207, D208, D209, D210, D211, D212, D213, D214, D215, D216, D217, D218, D219, D220, D221, D222, D223, D224, D225, D226: SK6812MINI-E; LED_SK6812MINI-E_3.2x2.8mm_P1.5mm_ReverseMount

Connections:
GND: C9.2, C10.2, C11.2, C12.2, C13.2, C14.2, C15.2, C16.2, C17.2, C18.2, C19.2, C20.2, C21.2, C22.2, C23.2, C24.2, C25.2, C26.2, C27.2, C28.2, C29.2, C30.2, C31.2, C32.2, C33.2, C34.2, C35.2, C36.2, C37.2, C38.2, C39.2, C40.2, C41.2, C42.2, C43.2, C44.2, C45.2, C46.2, C47.2, C48.2, C49.2, C50.2, C51.2, C52.2, C53.2, C54.2, C55.2, C56.2, C57.2, C58.2, C59.2, C60.2, C61.2, C62.2, C63.2, C64.2, C65.2, C66.2, C67.2, C68.2, C69.2, C70.2, C71.2, C72.2, C73.2, C74.2, C75.2, C76.2, C77.2, C78.2, C79.2, C80.2, C81.2, C82.2, C83.2, C84.2, C85.2, C86.2, C87.2, C88.2, C89.2, C90.2, C91.2, C92.2, C93.2, C94.2, C95.2, C96.2, C97.2, C98.2, C99.2, C100.2, C101.2, C102.2, C103.2, C104.2, C105.2, C106.2, C107.2, C108.2, C109.2, C110.2, C111.2, C112.2, C113.2, C114.2, C115.2, C116.2, C117.2, C118.2, C119.2, C120.2, D114.1 (VSS), D116.1 (VSS), D117.1 (VSS), D118.1 (VSS), D119.1 (VSS), D120.1 (VSS), D121.1 (VSS), D122.1 (VSS), D123.1 (VSS), D124.1 (VSS), D125.1 (VSS), D126.1 (VSS), D127.1 (VSS), D128.1 (VSS), D129.1 (VSS), D130.1 (VSS), D131.1 (VSS), D132.1 (VSS), D133.1 (VSS), D134.1 (VSS), D135.1 (VSS), D136.1 (VSS), D137.1 (VSS), D138.1 (VSS), D139.1 (VSS), D140.1 (VSS), D141.1 (VSS), D142.1 (VSS), D143.1 (VSS), D144.1 (VSS), D145.1 (VSS), D146.1 (VSS), D147.1 (VSS), D148.1 (VSS), D149.1 (VSS), D150.1 (VSS), D151.1 (VSS), D152.1 (VSS), D153.1 (VSS), D154.1 (VSS), D155.1 (VSS), D156.1 (VSS), D157.1 (VSS), D158.1 (VSS), D159.1 (VSS), D160.1 (VSS), D161.1 (VSS), D162.1 (VSS), D163.1 (VSS), D164.1 (VSS), D165.1 (VSS), D166.1 (VSS), D167.1 (VSS), D168.1 (VSS), D169.1 (VSS), D170.1 (VSS), D171.1 (VSS), D172.1 (VSS), D173.1 (VSS), D174.1 (VSS), D175.1 (VSS), D176.1 (VSS), D177.1 (VSS), D178.1 (VSS), D179.1 (VSS), D180.1 (VSS), D181.1 (VSS), D182.1 (VSS), D183.1 (VSS), D184.1 (VSS), D185.1 (VSS), D186.1 (VSS), D187.1 (VSS), D188.1 (VSS), D189.1 (VSS), D190.1 (VSS), D191.1 (VSS), D192.1 (VSS), D193.1 (VSS), D194.1 (VSS), D195.1 (VSS), D196.1 (VSS), D197.1 (VSS), D198.1 (VSS), D199.1 (VSS), D200.1 (VSS), D201.1 (VSS), D202.1 (VSS), D203.1 (VSS), D204.1 (VSS), D205.1 (VSS), D206.1 (VSS), D207.1 (VSS), D208.1 (VSS), D209.1 (VSS), D210.1 (VSS), D211.1 (VSS), D212.1 (VSS), D213.1 (VSS), D214.1 (VSS), D215.1 (VSS), D216.1 (VSS), D217.1 (VSS), D218.1 (VSS), D219.1 (VSS), D220.1 (VSS), D221.1 (VSS), D222.1 (VSS), D223.1 (VSS), D224.1 (VSS), D225.1 (VSS), D226.1 (VSS); also elsewhere on the board
LED3_DOUT: D116.4 (DOUT), D117.2 (DIN)
LED4_DOUT: D117.4 (DOUT), D118.2 (DIN)
LED5_DOUT: D118.4 (DOUT), D119.2 (DIN)
LED6_DOUT: D119.4 (DOUT), D120.2 (DIN)
LED7_DOUT: D120.4 (DOUT), D121.2 (DIN)
LED8_DOUT: D121.4 (DOUT), D122.2 (DIN)
LED9_DOUT: D122.4 (DOUT), D123.2 (DIN)
LED10_DOUT: D123.4 (DOUT), D124.2 (DIN)
LED11_DOUT: D124.4 (DOUT), D125.2 (DIN)
LED12_DOUT: D125.4 (DOUT), D126.2 (DIN)
LED13_DOUT: D126.4 (DOUT), D127.2 (DIN)
LED14_DOUT: D127.4 (DOUT), D128.2 (DIN)
LED15_DOUT: D128.4 (DOUT), D129.2 (DIN)
LED16_DOUT: D129.4 (DOUT), D130.2 (DIN)
LED17_DOUT: D130.4 (DOUT), D131.2 (DIN)
LED18_DOUT: D131.4 (DOUT), D132.2 (DIN)
LED19_DOUT: D132.4 (DOUT), D133.2 (DIN)
LED20_DOUT: D133.4 (DOUT), D134.2 (DIN)
LED21_DOUT: D134.4 (DOUT), D135.2 (DIN)
LED22_DOUT: D135.4 (DOUT), D136.2 (DIN)
LED23_DOUT: D136.4 (DOUT), D137.2 (DIN)
LED24_DOUT: D137.4 (DOUT), D138.2 (DIN)
LED25_DOUT: D138.4 (DOUT), D139.2 (DIN)
LED26_DOUT: D139.4 (DOUT), D140.2 (DIN)
LED27_DOUT: D140.4 (DOUT), D141.2 (DIN)
LED28_DOUT: D141.4 (DOUT), D142.2 (DIN)
LED29_DOUT: D142.4 (DOUT), D143.2 (DIN)
LED30_DOUT: D143.4 (DOUT), D144.2 (DIN)
LED31_DOUT: D144.4 (DOUT), D145.2 (DIN)
LED32_DOUT: D145.4 (DOUT), D146.2 (DIN)
LED33_DOUT: D146.4 (DOUT), D147.2 (DIN)
LED34_DOUT: D147.4 (DOUT), D148.2 (DIN)
LED35_DOUT: D148.4 (DOUT), D149.2 (DIN)
LED36_DOUT: D149.4 (DOUT), D150.2 (DIN)
LED37_DOUT: D150.4 (DOUT), D151.2 (DIN)
LED38_DOUT: D151.4 (DOUT), D152.2 (DIN)
LED39_DOUT: D152.4 (DOUT), D153.2 (DIN)
LED40_DOUT: D153.4 (DOUT), D154.2 (DIN)
LED41_DOUT: D154.4 (DOUT), D155.2 (DIN)
LED42_DOUT: D155.4 (DOUT), D156.2 (DIN)
LED43_DOUT: D156.4 (DOUT), D157.2 (DIN)
LED44_DOUT: D157.4 (DOUT), D158.2 (DIN)
LED45_DOUT: D158.4 (DOUT), D159.2 (DIN)
LED46_DOUT: D159.4 (DOUT), D160.2 (DIN)
LED47_DOUT: D160.4 (DOUT), D161.2 (DIN)
LED48_DOUT: D161.4 (DOUT), D162.2 (DIN)
LED49_DOUT: D162.4 (DOUT), D163.2 (DIN)
LED50_DOUT: D163.4 (DOUT), D164.2 (DIN)
LED51_DOUT: D164.4 (DOUT), D165.2 (DIN)
LED52_DOUT: D165.4 (DOUT), D166.2 (DIN)
LED53_DOUT: D166.4 (DOUT), D167.2 (DIN)
LED54_DOUT: D167.4 (DOUT), D168.2 (DIN)
LED55_DOUT: D168.4 (DOUT), D169.2 (DIN)
LED56_DOUT: D169.4 (DOUT), D170.2 (DIN)
LED57_DOUT: D170.4 (DOUT), D171.2 (DIN)
LED58_DOUT: D171.4 (DOUT), D172.2 (DIN)
LED59_DOUT: D172.4 (DOUT), D173.2 (DIN)
LED60_DOUT: D173.4 (DOUT), D174.2 (DIN)
LED61_DOUT: D174.4 (DOUT), D175.2 (DIN)
LED62_DOUT: D175.4 (DOUT), D176.2 (DIN)
LED63_DOUT: D176.4 (DOUT), D177.2 (DIN)
LED64_DOUT: D177.4 (DOUT), D178.2 (DIN)
LED65_DOUT: D178.4 (DOUT), D179.2 (DIN)
LED66_DOUT: D179.4 (DOUT), D180.2 (DIN)
LED67_DOUT: D180.4 (DOUT), D181.2 (DIN)
LED68_DOUT: D181.4 (DOUT), D182.2 (DIN)
LED69_DOUT: D182.4 (DOUT), D183.2 (DIN)
LED70_DOUT: D183.4 (DOUT), D184.2 (DIN)
LED71_DOUT: D184.4 (DOUT), D185.2 (DIN)
LED72_DOUT: D185.4 (DOUT), D186.2 (DIN)
LED73_DOUT: D186.4 (DOUT), D187.2 (DIN)
LED74_DOUT: D187.4 (DOUT), D188.2 (DIN)
LED75_DOUT: D188.4 (DOUT), D189.2 (DIN)
LED76_DOUT: D189.4 (DOUT), D190.2 (DIN)
LED77_DOUT: D190.4 (DOUT), D191.2 (DIN)
LED78_DOUT: D191.4 (DOUT), D192.2 (DIN)
LED79_DOUT: D192.4 (DOUT), D193.2 (DIN)
LED80_DOUT: D193.4 (DOUT), D194.2 (DIN)
LED81_DOUT: D194.4 (DOUT), D195.2 (DIN)
LED82_DOUT: D195.4 (DOUT), D196.2 (DIN)
LED83_DOUT: D196.4 (DOUT), D197.2 (DIN)
LED84_DOUT: D197.4 (DOUT), D198.2 (DIN)
LED85_DOUT: D198.4 (DOUT), D199.2 (DIN)
LED86_DOUT: D199.4 (DOUT), D200.2 (DIN)
LED87_DOUT: D200.4 (DOUT), D201.2 (DIN)
LED88_DOUT: D201.4 (DOUT), D202.2 (DIN)
LED89_DOUT: D202.4 (DOUT), D203.2 (DIN)
LED90_DOUT: D203.4 (DOUT), D204.2 (DIN)
LED91_DOUT: D204.4 (DOUT), D205.2 (DIN)
LED92_DOUT: D205.4 (DOUT), D206.2 (DIN)
LED93_DOUT: D206.4 (DOUT), D207.2 (DIN)
LED94_DOUT: D207.4 (DOUT), D208.2 (DIN)
LED95_DOUT: D208.4 (DOUT), D209.2 (DIN)
LED96_DOUT: D209.4 (DOUT), D210.2 (DIN)
LED97_DOUT: D210.4 (DOUT), D211.2 (DIN)
LED98_DOUT: D211.4 (DOUT), D212.2 (DIN)
LED99_DOUT: D212.4 (DOUT), D213.2 (DIN)
LED100_DOUT: D213.4 (DOUT), D214.2 (DIN)
LED101_DOUT: D214.4 (DOUT), D215.2 (DIN)
LED102_DOUT: D215.4 (DOUT), D216.2 (DIN)
LED103_DOUT: D216.4 (DOUT), D217.2 (DIN)
LED104_DOUT: D217.4 (DOUT), D218.2 (DIN)
LED105_DOUT: D218.4 (DOUT), D219.2 (DIN)
LED106_DOUT: D219.4 (DOUT), D220.2 (DIN)
LED107_DOUT: D220.4 (DOUT), D221.2 (DIN)
LED108_DOUT: D221.4 (DOUT), D222.2 (DIN)
LED109_DOUT: D222.4 (DOUT), D223.2 (DIN)
LED110_DOUT: D223.4 (DOUT), D224.2 (DIN)
LED111_DOUT: D224.4 (DOUT), D225.2 (DIN)
LED112_DOUT: D225.4 (DOUT), D226.2 (DIN)
VBUS: C9.1, C10.1, C11.1, C12.1, C13.1, C14.1, C15.1, C16.1, C17.1, C18.1, C19.1, C20.1, C21.1, C22.1, C23.1, C24.1, C25.1, C26.1, C27.1, C28.1, C29.1, C30.1, C31.1, C32.1, C33.1, C34.1, C35.1, C36.1, C37.1, C38.1, C39.1, C40.1, C41.1, C42.1, C43.1, C44.1, C45.1, C46.1, C47.1, C48.1, C49.1, C50.1, C51.1, C52.1, C53.1, C54.1, C55.1, C56.1, C57.1, C58.1, C59.1, C60.1, C61.1, C62.1, C63.1, C64.1, C65.1, C66.1, C67.1, C68.1, C69.1, C70.1, C71.1, C72.1, C73.1, C74.1, C75.1, C76.1, C77.1, C78.1, C79.1, C80.1, C81.1, C82.1, C83.1, C84.1, C85.1, C86.1, C87.1, C88.1, C89.1, C90.1, C91.1, C92.1, C93.1, C94.1, C95.1, C96.1, C97.1, C98.1, C99.1, C100.1, C101.1, C102.1, C103.1, C104.1, C105.1, C106.1, C107.1, C108.1, C109.1, C110.1, C111.1, C112.1, C113.1, C114.1, C115.1, C116.1, C117.1, C118.1, C119.1, C120.1, D114.3 (VDD), D116.3 (VDD), D117.3 (VDD), D118.3 (VDD), D119.3 (VDD), D120.3 (VDD), D121.3 (VDD), D122.3 (VDD), D123.3 (VDD), D124.3 (VDD), D125.3 (VDD), D126.3 (VDD), D127.3 (VDD), D128.3 (VDD), D129.3 (VDD), D130.3 (VDD), D131.3 (VDD), D132.3 (VDD), D133.3 (VDD), D134.3 (VDD), D135.3 (VDD), D136.3 (VDD), D137.3 (VDD), D138.3 (VDD), D139.3 (VDD), D140.3 (VDD), D141.3 (VDD), D142.3 (VDD), D143.3 (VDD), D144.3 (VDD), D145.3 (VDD), D146.3 (VDD), D147.3 (VDD), D148.3 (VDD), D149.3 (VDD), D150.3 (VDD), D151.3 (VDD), D152.3 (VDD), D153.3 (VDD), D154.3 (VDD), D155.3 (VDD), D156.3 (VDD), D157.3 (VDD), D158.3 (VDD), D159.3 (VDD), D160.3 (VDD), D161.3 (VDD), D162.3 (VDD), D163.3 (VDD), D164.3 (VDD), D165.3 (VDD), D166.3 (VDD), D167.3 (VDD), D168.3 (VDD), D169.3 (VDD), D170.3 (VDD), D171.3 (VDD), D172.3 (VDD), D173.3 (VDD), D174.3 (VDD), D175.3 (VDD), D176.3 (VDD), D177.3 (VDD), D178.3 (VDD), D179.3 (VDD), D180.3 (VDD), D181.3 (VDD), D182.3 (VDD), D183.3 (VDD), D184.3 (VDD), D185.3 (VDD), D186.3 (VDD), D187.3 (VDD), D188.3 (VDD), D189.3 (VDD), D190.3 (VDD), D191.3 (VDD), D192.3 (VDD), D193.3 (VDD), D194.3 (VDD), D195.3 (VDD), D196.3 (VDD), D197.3 (VDD), D198.3 (VDD), D199.3 (VDD), D200.3 (VDD), D201.3 (VDD), D202.3 (VDD), D203.3 (VDD), D204.3 (VDD), D205.3 (VDD), D206.3 (VDD), D207.3 (VDD), D208.3 (VDD), D209.3 (VDD), D210.3 (VDD), D211.3 (VDD), D212.3 (VDD), D213.3 (VDD), D214.3 (VDD), D215.3 (VDD), D216.3 (VDD), D217.3 (VDD), D218.3 (VDD), D219.3 (VDD), D220.3 (VDD), D221.3 (VDD), D222.3 (VDD), D223.3 (VDD), D224.3 (VDD), D225.3 (VDD), D226.3 (VDD); also elsewhere on the board

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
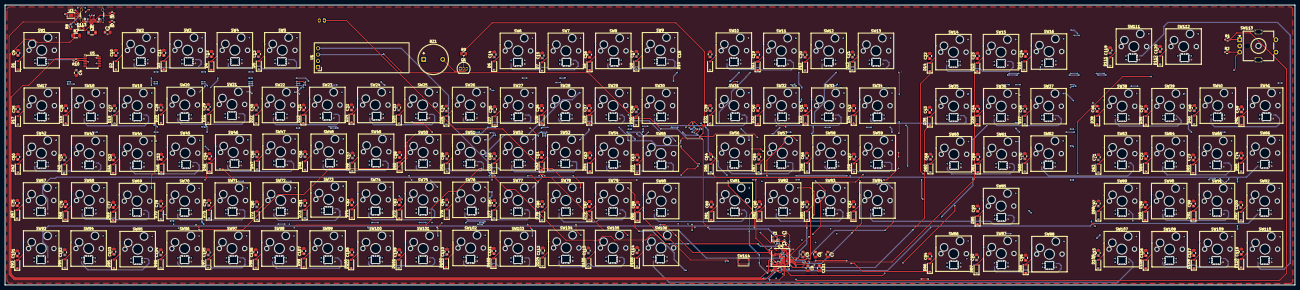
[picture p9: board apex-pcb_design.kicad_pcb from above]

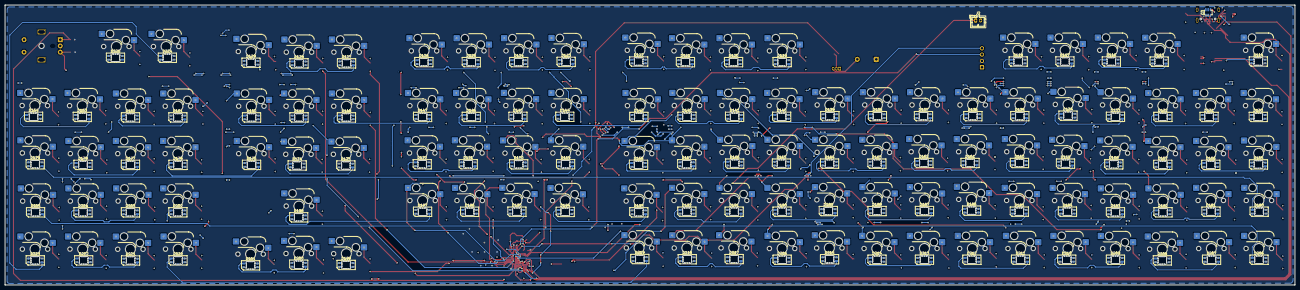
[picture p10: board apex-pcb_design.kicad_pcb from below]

Board: 4 copper layers, 516.6 x 112.1 mm, 479 parts (114 on the bottom side), 269 nets.

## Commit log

2026-08-01 Update Journal with resources and images for keyboard build
    Added links to documentation and guides for keyboard configuration and OLED schematic. Included images for reference.
2026-08-06 Designing the schematic
    Added images and comments about the MCU and key construction.
2026-08-07 ESP32-S3 schematic
2026-08-09 Building the charger
2026-08-09 Voltage Regulator LED
2026-08-13 Schematic LEDS
2026-08-14 Completetion LEDs
2026-08-14 Schematic complete
    I finally completed the schematic ayaya
2026-08-14 PCB designing start
    Wish me luck team
2026-08-24 PCB progress...
    Routing is just pure headache and HELLLLL
